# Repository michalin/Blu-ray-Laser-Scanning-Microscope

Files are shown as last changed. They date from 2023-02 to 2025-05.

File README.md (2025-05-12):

# Blu-ray Laser Microscope
In a way, CD-ROM and Blu-Ray drives already function like microscopes, using lasers to read the microscopic pits and lands on the surface of a CD or DVD. In the case of a Blu-Ray drive, an ultra precise blue (technically closer to violet in color) laser with a wavelength of 405 nanometers is focused on the surface of a disc, and how effectively that light is reflected back to the drive’s optical pickup unit determines whether a one or a zero has been detected.
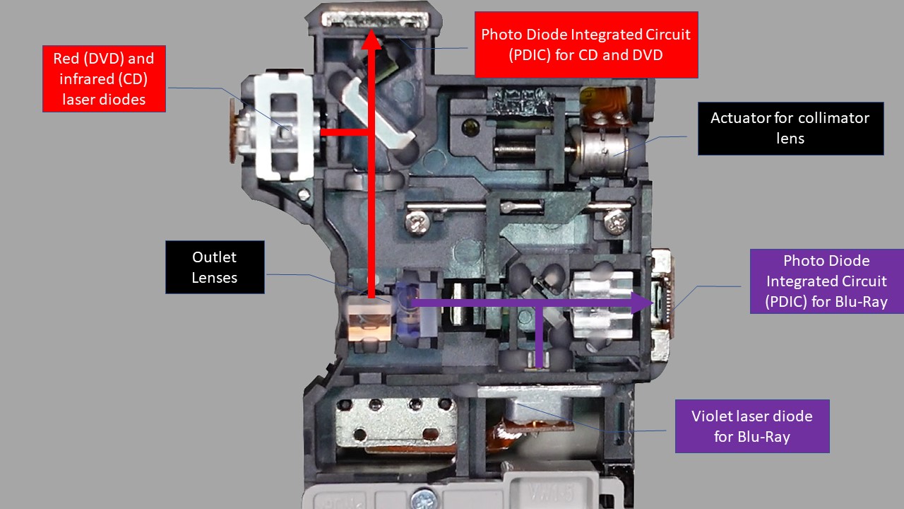
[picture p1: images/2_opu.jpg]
*Combined CD/DVD and Blu-ray optical pickup unit used in the project (BDP-10G)*</img>

But the sensors in the optical pickup unit can actually measure a wider range of light intensities—not just on or off— which facilitates a Blu-Ray drive’s error correction capabilities, and allows for the hardware to be repurposed for other uses. This is about repurposing a Blu-Ray pickup to build a simple scanning laser microscope. 
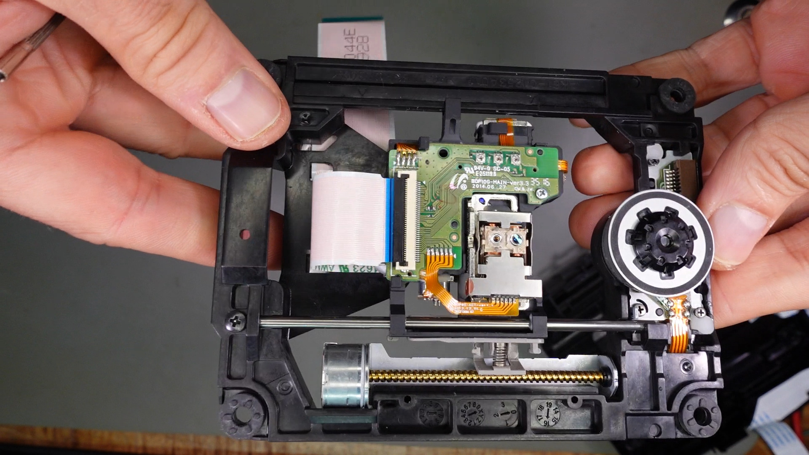
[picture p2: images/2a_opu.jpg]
*CD/DVD/Blu-ray drive with pickup from Samsung BD-J5900*</img>

A couple of custom-designed and manufactured plastic parts create a scanning bed for a sample that could move back in forth in one Y-direction (frame), while the laser itself shifted back and forth in x-direction (lines) by its surrounding "voice" coils.
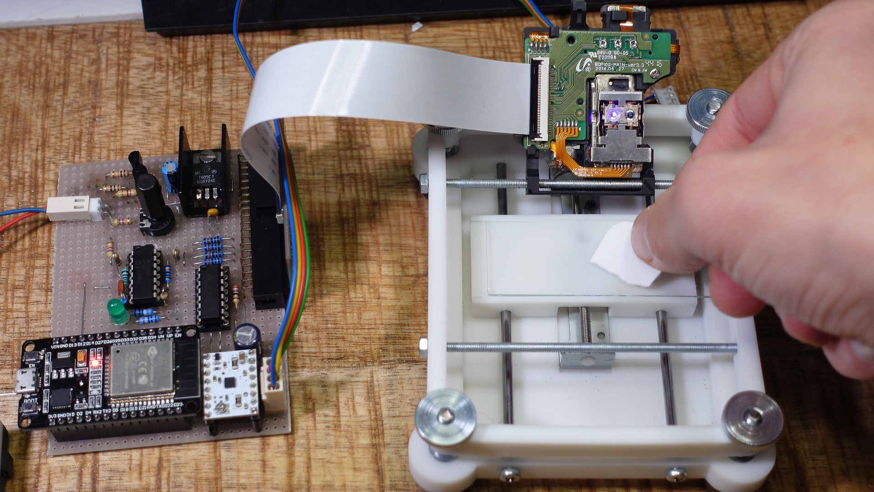
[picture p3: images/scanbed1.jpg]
*Scanning bed with electronics*</img>

Unlike an optical microscope, where the entirely of an object is imaged at once, a scanning laser microscope takes light intensity measurements in increments, moving across an object in a grid and assembling a magnified image pixel by pixel. 
A browser-based user interface written in HTML an Java Script allows to operate the device over WLAN.
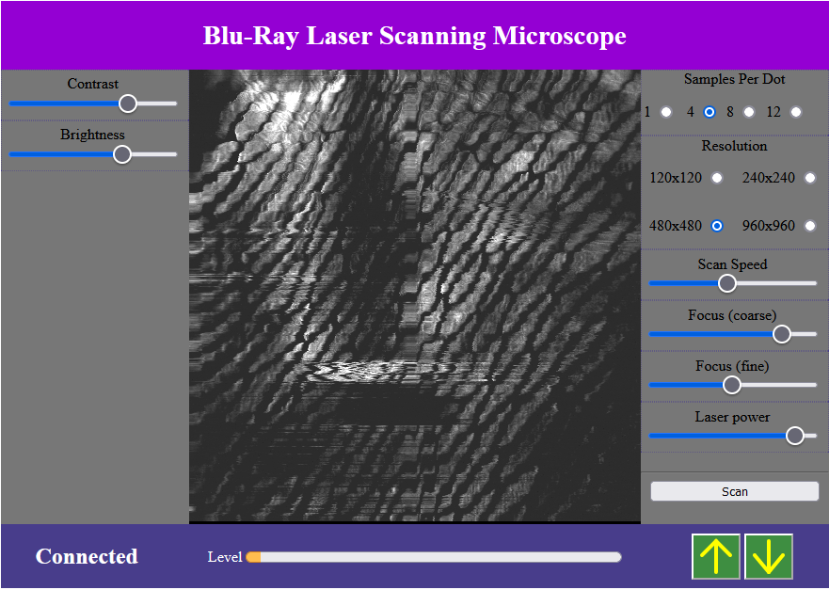
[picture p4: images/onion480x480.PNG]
*Web interface of Blu-ray microscope, showing onion cells*</img>

## Important Note
**The ESP32 API has changed from versions 2.X (based on ESP-IDF 4.4) to version 3.0 (based on ESP-IDF 5.1) of the Arduino ESP32 core. Only compiles against version 2.X.
Find more information here: [Migration from 2.x to 3.0](https://docs.espressif.com/projects/arduino-esp32/en/latest/migration_guides/2.x_to_3.0.html)**

---
## Preparing The Microscope
- Enter WLAN SSID and passphrase into the source code file `src.ino` and upload to ESP32 module.
- Copy `index.htm` and `opencv.js` to any directory on your PC and open `index.html` in your web browser.
- Adjust the reference voltage for the op-amps with Trimmer RV1 until the LED goes off and the level indicator on the bottom of the user interface shows a minimum.
- Adjust the current through the stepper motor with the trimmer on the STSPIN 220 driver module while the Up or Down button on the website is pressed until the object sled just moves smoothly. Warning: Too much current will overheat and burn the motor out.
- Place a slide in the recess of the specimen slide and a piece of paper on it. Flip down the OPU and turn the thumbscrews until the LED lights up.
---

## Taking Images
- Set the laser power and focus controls to their full extent
- Peep through the pickup lens from above and carefully position the specimen by hand and with the Up and Down buttons on the web interface until it is correctly placed.
- Slowly turn back the coarse focus control until the indicator swings out. Then adjust it with the fine focus control and the laser power control until it deflects about halfway.
- Perform a trial scan at low resolution and high scan speed. You can also adjust the parameters during the scan.
- Now try higher resolutions and/or lower scan speed and/or samples per dot to get a higher image quality.
  
---
## Watch Videos to Learn More
In Part one you will learn how I re-engineered an optical pickup unit from a broken Blu-ray player so that it can be used for a laser scanning microscope.  

<a href="https://youtu.be/liGuhbFh4IQ" alt="DIY Blu-Ray Laser Scanning Microscope #1: Making a Laser Microphone">
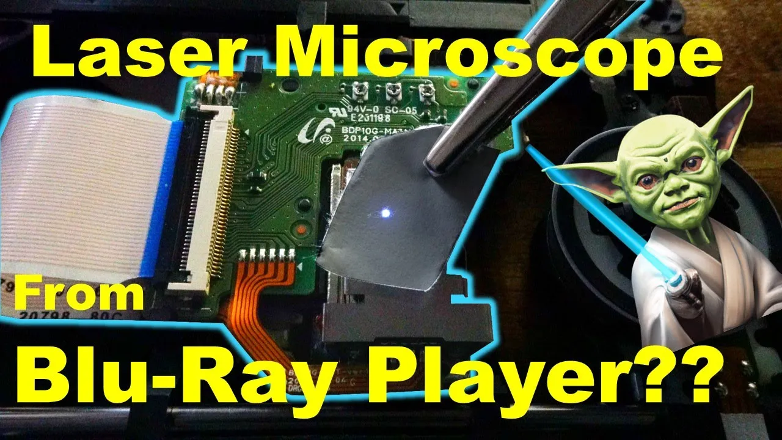
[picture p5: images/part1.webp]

</a>  

---
Part 2 is about a working prototype that builds on the existing CD/DVD/Blu-ray drive I salvaged from the Blu-ray player.  
<a href="https://youtu.be/Hkialty_8K4" alt="DIY Blu-Ray Laser Scanning Microscope #2: Shooting Images">
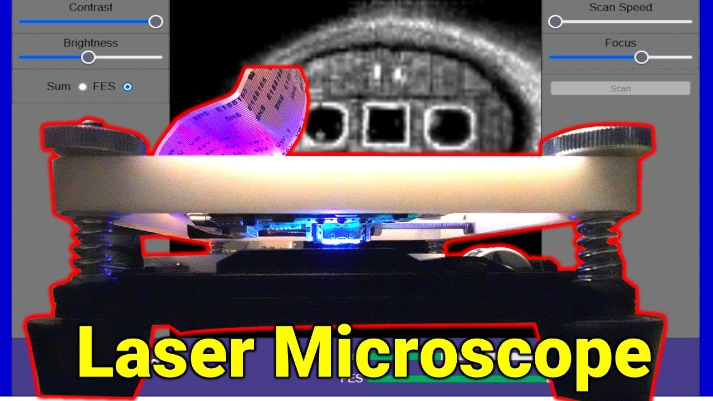
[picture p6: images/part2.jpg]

</a>

---
Part 3 shows how to build an improved version of the microscope from 3D printed parts and how to use it.  
<a href="https://youtu.be/xfuWbnMYOos" alt="DIY Blu-Ray Laser Scanning Microscope #3: Improvements And Tests">
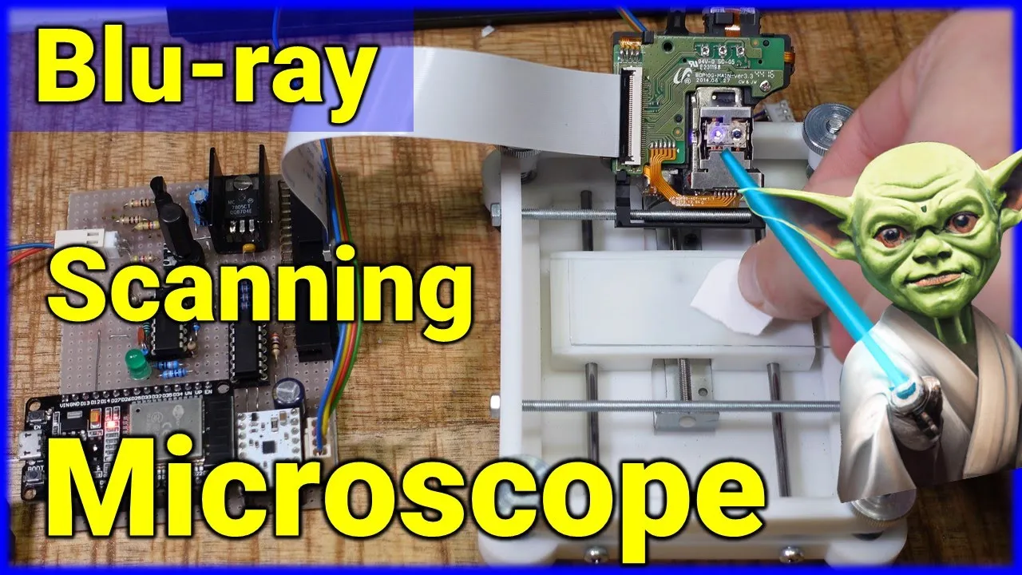
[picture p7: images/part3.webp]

</a>

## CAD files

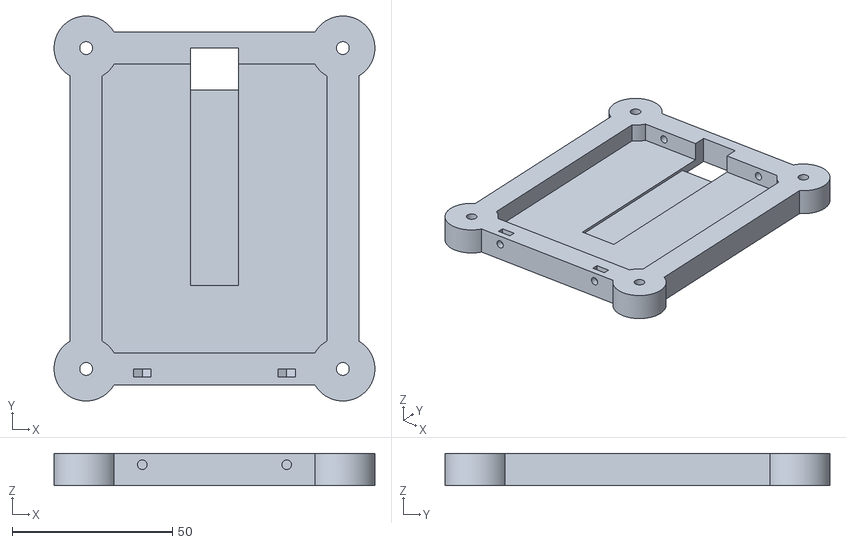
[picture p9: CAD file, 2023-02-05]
cad/bottom (Meshed).stl
100.0 x 120.0 x 10.0

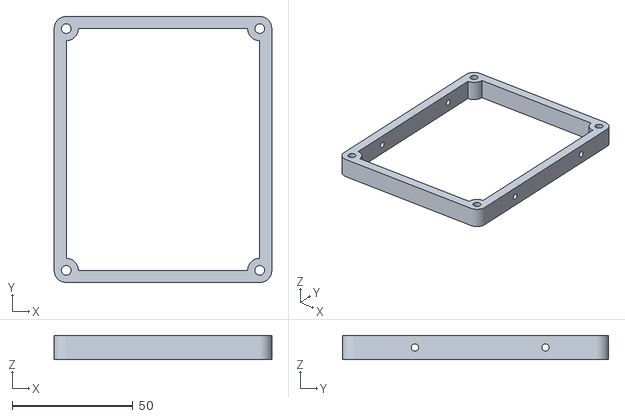
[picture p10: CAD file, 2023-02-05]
cad/top (Meshed).stl
90.0 x 110.0 x 10.0

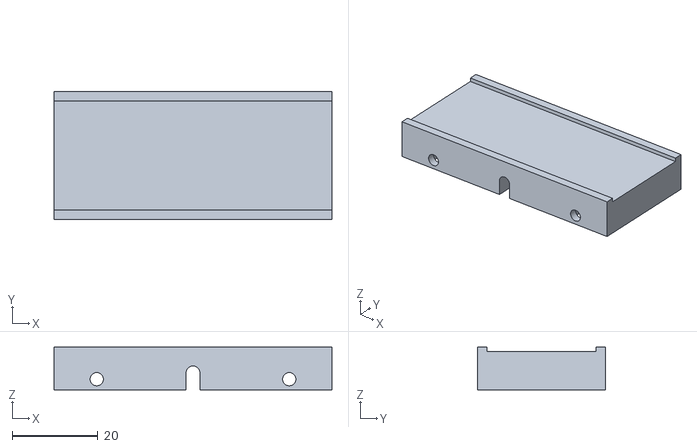
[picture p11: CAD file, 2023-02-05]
cad/obj_sled (Meshed).stl
65.0 x 30.0 x 10.0

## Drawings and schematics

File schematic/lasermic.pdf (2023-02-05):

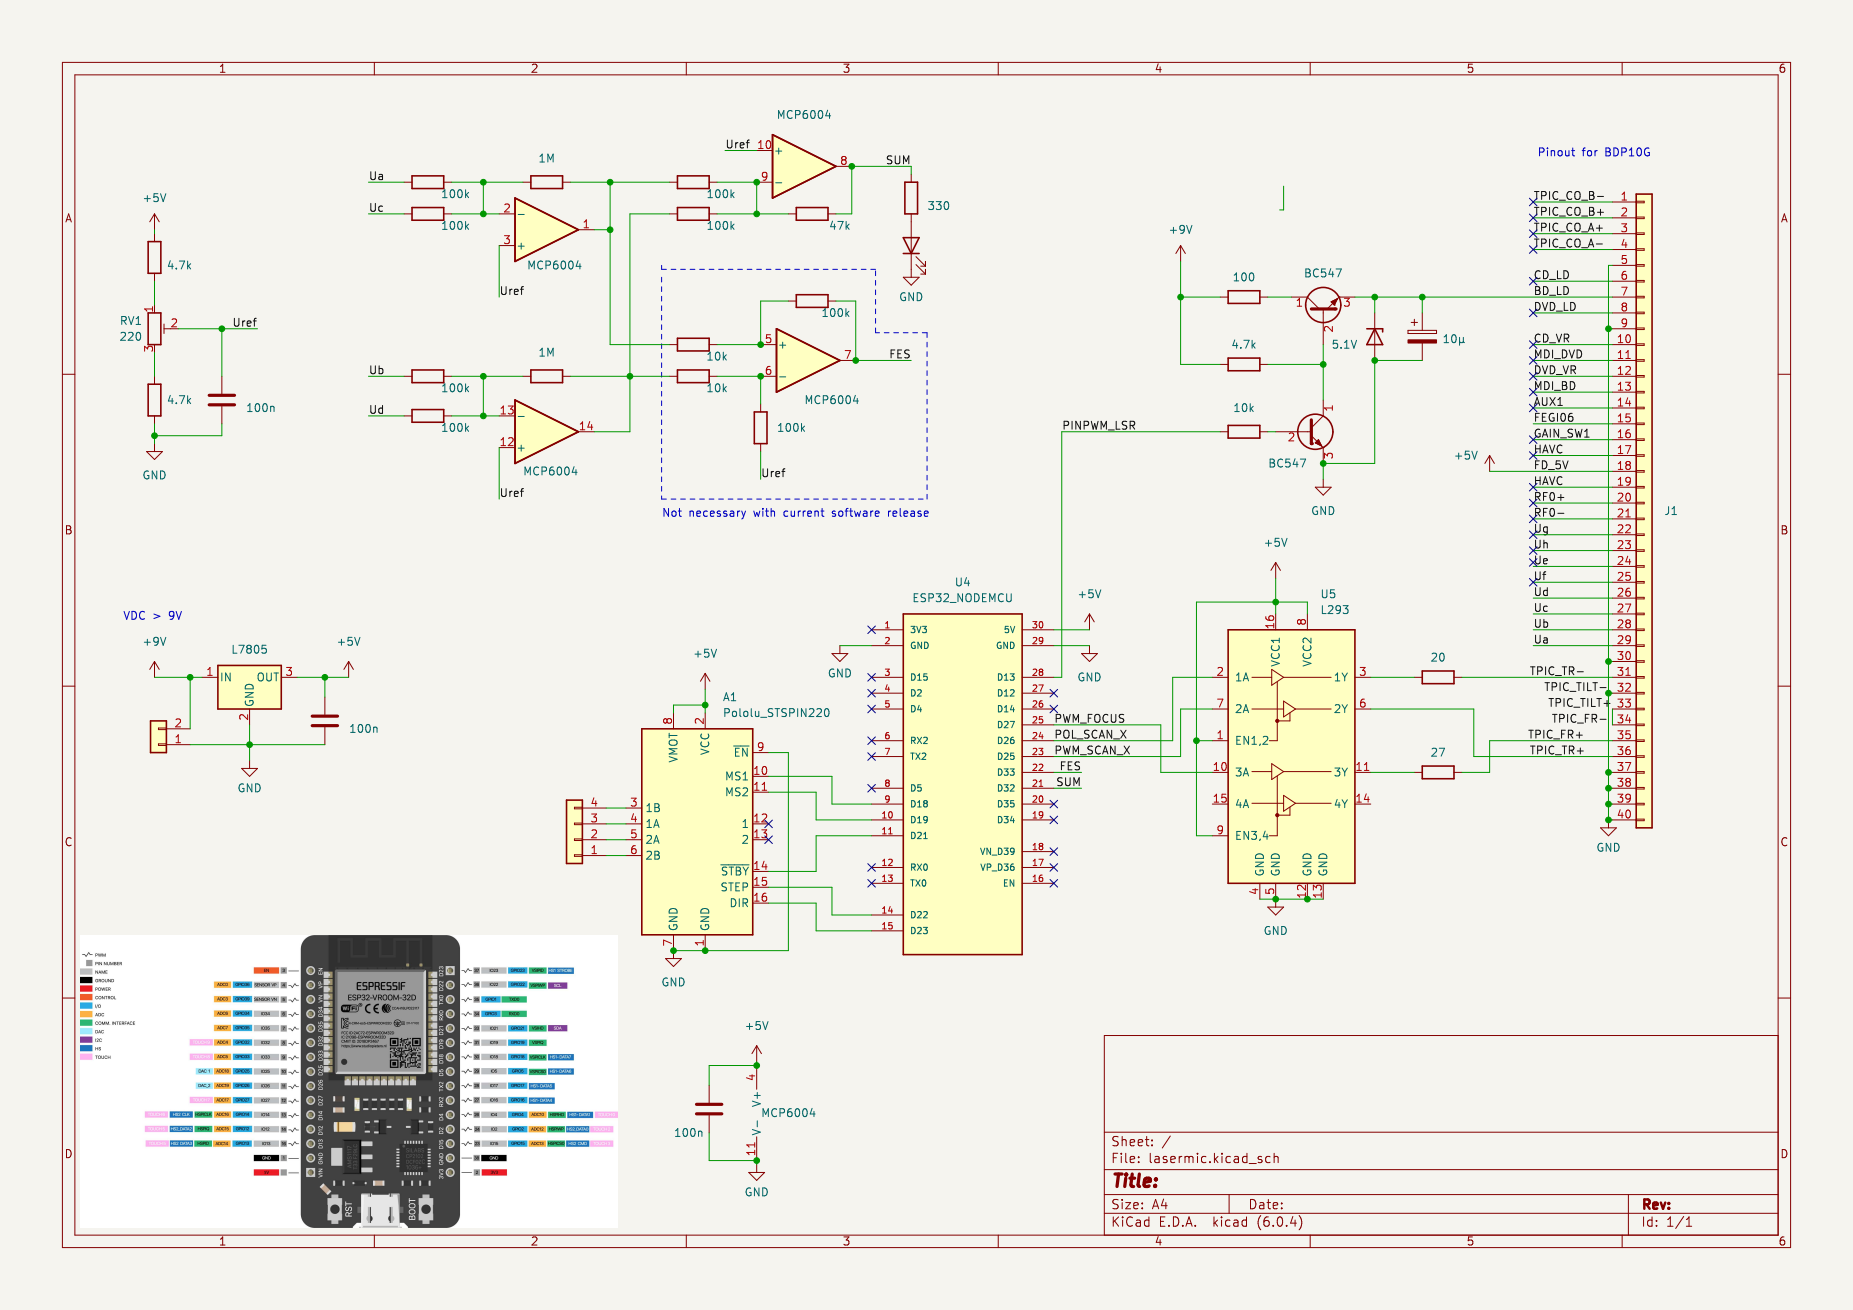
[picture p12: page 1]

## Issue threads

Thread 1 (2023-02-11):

Youtube images aren't showing up on ReadMe

zombodotcom, 2023-02-11:
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

this should fix it if you copy the markdown.

---
## Watch Videos to Learn More
In Part 1 you will see how I re-engineered an optical pickup unit from a broken Blu-ray player so that it can be used for a laser scanning microscope.

<a href="https://youtu.be/liGuhbFh4IQ" alt="DIY Blu-Ray Laser Scanning Microscope #1: Making a Laser Microphone">
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
</a>

---
Part 2 is about a working prototype that builds on the existing CD/DVD/Blu-ray drive I salvaged from the Blu-ray player.

<a href="https://youtu.be/Hkialty_8K4" alt="DIY Blu-Ray Laser Scanning Microscope #2: Shooting Images">
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
</a>

---
Part 3 shows how to build an improved version of the microscope from 3D printed parts and how to use it.

<a href="https://youtu.be/xfuWbnMYOos" alt="DIY Blu-Ray Laser Scanning Microscope #3: Improvements And Tests">
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
</a>

michalin, 2023-02-12:
Thank you. I fixed it.

Closed 2023-02-12.

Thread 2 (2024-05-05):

TPIC Resistor Value

SphaeroX, 2024-05-05:
R11 and R14 got no Footprints, but the value of 20 ad 27, is this the right resistor value?

i try to build a PCB for PCBWay, but i saw those are not connected.

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

michalin, 2024-05-06:
Yes, these are the values.

SphaeroX, 2024-05-14:
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

Here i am so far but i dont find any R20 and R27, can i use also R22 and R33 ?

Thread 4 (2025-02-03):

Pinout naming scheme

Caraffa-git, 2025-02-03:
Hi @michalin ,
could you please clarify the meaning of the labels in your schematic? The current names are not very intuitive, and I'm having trouble understanding the function of some pins:
- POL_SCAN_X
- PWM_SCAN_X
- TPIC_TR +/-
- TPIC_FT +/-

Also, why are TPIC_TILT+ and TPIC_FR- shorted together?

Your explanation would be much appreciated. Thanks!

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

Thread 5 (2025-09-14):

voice coil motor

GItWPP, 2025-09-14:
Hi there, I'm an electronics enthusiast looking to replicate your Blu-ray Laser Scanning Microscope project. I'm encountering some issues with the voice coil motor control. I see you've achieved up/down, left/right, and tilt movements for the voice coil motor, but this functionality isn't covered in the open-source documentation. Could you provide the source code for this part? Thanks!

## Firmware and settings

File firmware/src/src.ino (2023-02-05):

/* Copyright (C) 2022  Doctor Volt

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
 You should have received a copy of the GNU General Public License
 along with this program.  If not, see <https://www.gnu.org/licenses/>.
*/

// #include <Arduino.h>
#include <ArduinoJson.h>
//#include "driver/ledc.h"

#define PINSTEPY_M1 18
#define PINSTEPY_M2 19
#define PINSTEPY_SLP 21
#define PINSTEPY_DIR 22
#define PINSTEPY_STP 23
#define PINPWM_SCAN_X 25
#define PINPOL_SCAN_X 26
#define PINPWN_FOCUS 27

#define PIN_SUM 32
#define PIN_FES 33
#define PINPWM_LSR 13
#define ACTIVE LOW
#define PASSIVE HIGH
#define MAX_SAMPLES 16
enum CMD
{
  CMD_IDLE,
  SCAN,
  STOP,
  FOCUS,
  GO_UP,
  GO_DN,
  GO_STOP
};
#define DIRY_UP 1
#define DIRY_DN 0
#define PWM_SCN_MAX_BITS 9
#define PWM_FOC_BITS 10
#define PWM_LSR_BITS 8


const char *ssid = "WLAN-KEY";
const char *password = "passphrase";
// const int ledPin = LED_BUILTIN;
const int PWMScnFreq = 40000000 >> PWM_SCN_MAX_BITS; // PWM Frequency for X-Scan for max. resolution
const int PWMChanScn = 0;     // PWM Channel for X-Scan
const int PWMFocFreq = 40000000 >> PWM_FOC_BITS;
const int PWMChanFoc = 2; // PWM Channel for focus
const int PWMLsrFreq = 100000;
const int PWMChanLsr = 4; // PWM Channel for laser
const int PWMChanSld = 6; // PWM Channel for manual sled positioning
int PWMRes;               // = (1 << PWMResBits) - 1;
int resolution;           // = 2 * (1 << PWMResBits) - 1;
// int YRes;
int scan_speed;
int nsamples; // Samples per dot for averaging
struct /*__attribute__((__packed__))*/ Point
{
  uint16_t C1;
  // uint16_t C2;
};
typedef uint16_t CVPoint;
CVPoint *linebuf;
portMUX_TYPE timerMux = portMUX_INITIALIZER_UNLOCKED;
volatile SemaphoreHandle_t scanSemaphore;
TaskHandle_t taskHandle;

// Function declarations for web.cpp
void web_init(const char *ssid, const char *password);
void web_write(const char *data);
// void web_write_event(const char *event);
void web_cleanup();

// void scan_(void*);

// Macro to configure the STSPIN220 for 64 microsteps
#define STS220SET                      \
  digitalWrite(PINSTEPY_SLP, ACTIVE);  \
  digitalWrite(PINSTEPY_STP, LOW);     \
  digitalWrite(PINSTEPY_DIR, HIGH);    \
  digitalWrite(PINSTEPY_SLP, PASSIVE); \
  vTaskDelay(10);

void setXscan(int x) // Position of lens
{
  int d;
  if (x >= 0)
  {
    d = PWMRes - x - resolution / 30; // The "resolution/xx fixes the glitch arond the zero position"
    digitalWrite(PINPOL_SCAN_X, HIGH);
  }
  else
  {
    d = -x;
    digitalWrite(PINPOL_SCAN_X, LOW);
  }
  //  int d = (x >= 0) ? PWMRes - x : -x;
  //Serial.printf("x: %d, d: %d\n", x, d);
  //  digitalWrite(PINPOL_SCAN_X, (x >= 0));
  ledcWrite(PWMChanScn, d);
}

void scanX(int speed, CVPoint *linebuf)
{
  for (int i = 1; i <= 16; i++) // Move back lens smoothly before scanning to prevent bouncing
  {
    setXscan(-i * resolution / 32);
    // Serial.printf("%d", -i*PWMRes/8);
    vTaskDelay(10);
  }
  for (int scanX = -resolution / 2; scanX <= resolution / 2 - 1; scanX++)
  {
    setXscan(scanX);
    delayMicroseconds(1550 - 100 * speed);
    int c1 = 0;
    for (int i = 0; i < nsamples; i++)
    {
      c1 += analogRead(PIN_SUM);
      // c2 += analogRead(PIN_FES);
    }
    linebuf[resolution / 2 + scanX] = 16 * (c1 / nsamples); // Sum
  }
  setXscan(0); //Neutral position
}

/* This must be started as task to prevent triggering the async_tcp watchdog*/
void scan(void *task_break)
{
  const int nSteps = 1280;   // Will do one revolution (20*64 microsteps)
  static int microsteps = 0; // Number of microsteps passed
  const int pre_steps = 200;  // Number of steps the motor takes before scanning for the leadscrew to gain grip.
  Serial.println("Start scanning");
  STS220SET

  int yskip = 1 + floor(nSteps / (PWMRes + 1));

  digitalWrite(PINSTEPY_DIR, DIRY_UP);
  for (int i = 0; i < yskip * resolution / 2; i++)
  {
    digitalWrite(PINSTEPY_STP, HIGH);
    vTaskDelay(1);
    digitalWrite(PINSTEPY_STP, LOW);
    vTaskDelay(1);
    microsteps--;
  }
  // Advance the sled a bit, so that the leadscrew gets grip.
  digitalWrite(PINSTEPY_DIR, DIRY_DN);
  for (int i = 0; i < pre_steps / yskip; i++)
  {
    digitalWrite(PINSTEPY_STP, HIGH);
    vTaskDelay(1);
    digitalWrite(PINSTEPY_STP, LOW);
    vTaskDelay(1);
    microsteps++;
  }

  for (int i = 0; (i < resolution) && (!*((bool *)task_break)); i++)
  {
    scanX(scan_speed, linebuf);     // Scan line Forwards
    for (int i = 0; i < yskip; i++) // Forward by ySkip microsteps
    {
      digitalWrite(PINSTEPY_STP, HIGH);
      vTaskDelay(1);
      digitalWrite(PINSTEPY_STP, LOW);
      vTaskDelay(1);
      microsteps++;
    }
    xSemaphoreGive(scanSemaphore); // This triggers sending of the line in the loop() function
    vTaskSuspend(NULL);            // Suspend task during data transfer
    //if(*(bool*)task_break) break;
  }
  Serial.printf("Scan completed: %d\n", *((bool *)task_break));

  // Move sled back to intitial y position
  digitalWrite(PINSTEPY_DIR, DIRY_UP);
  for (int i = 0; i < microsteps; i++)
  {
    digitalWrite(PINSTEPY_STP, HIGH);
    delayMicroseconds(200);
    digitalWrite(PINSTEPY_STP, LOW);
    delayMicroseconds(200);
  }
  microsteps = 0;
  digitalWrite(PINSTEPY_SLP, ACTIVE);
  digitalWrite(PINPWM_SCAN_X, LOW);
  ledcWrite(PWMChanScn, 0);
  digitalWrite(PINPOL_SCAN_X, LOW);
  web_write("stop");
  vTaskDelete(NULL);
}

void handleWebMessage(const char *data, size_t len)
{
  DynamicJsonDocument jdoc(1024);
  deserializeJson(jdoc, data);
  static bool taskBreak;

  if (nsamples != (int)jdoc["nsamples"])
  {
    nsamples = jdoc["nsamples"];
    // Serial.printf("Number of samples per dot: %d\n", nsamples);
  }
  if (scan_speed != (int)jdoc["speed"])
  {
    scan_speed = jdoc["speed"];
    // Serial.printf("speed: %d\n", scan_speed);
  }
  static int pwmbits;
  if (pwmbits != (int)jdoc["pwmbits"])
  {
    pwmbits = jdoc["pwmbits"];
    Serial.printf("pwmbits: %d\n", pwmbits);
    ledcSetup(PWMChanScn, PWMScnFreq, pwmbits);
    PWMRes = (1 << pwmbits) - 1;
    resolution = 2 * (1 << pwmbits) - (1 << pwmbits - 3);
    Serial.printf("Resolution: %d\n", resolution);
  }
  static int focus;
  if (focus != (int)jdoc["focus"])
  {
    focus = jdoc["focus"];
    // Serial.printf("focus: %d\n", focus);
    ledcWrite(PWMChanFoc, focus);
  }
  static int laser;
  if (laser != (int)jdoc["laser"])
  {
    laser = jdoc["laser"];
    // Serial.printf("laser: %d\n", laser);
    ledcWrite(PWMChanLsr, laser);
  }
  static int xcoil;
  if (xcoil != (int)jdoc["xcoil"])
  {
    xcoil = jdoc["xcoil"];
    Serial.printf("xcoil: %d\n", xcoil);
    setXscan(xcoil);
  }

  switch ((int)jdoc["cmd"])
  {
  case CMD::SCAN:
    taskBreak = 0;
    xTaskCreate(scan, "scan", 16000, &taskBreak, 1, &taskHandle);
    break;
  case CMD::STOP:
    taskBreak = 1;
    break;
  case CMD::GO_UP:
  case CMD::GO_DN:
    // Serial.print("Move Sled ");
    STS220SET;
    (int)jdoc["cmd"] == GO_UP
        ? digitalWrite(PINSTEPY_DIR, DIRY_UP)
        : digitalWrite(PINSTEPY_DIR, DIRY_DN);
    ledcAttachPin(PINSTEPY_STP, PWMChanSld);
    ledcWriteTone(PWMChanSld, 100 * (scan_speed + 1));
    break;
  case CMD::GO_STOP:
    // Serial.println("Stop sled");
    ledcDetachPin(PINSTEPY_STP);
    digitalWrite(PINSTEPY_SLP, ACTIVE);
    break;
  }
}

/*void ARDUINO_ISR_ATTR onTimer()
{
  portENTER_CRITICAL_ISR(&timerMux);
  portEXIT_CRITICAL_ISR(&timerMux);
  xSemaphoreGiveFromISR(timerSemaphore, NULL);
}*/

void setup()
{
  Serial.begin(115200);
  // digitalWrite(ledPin, LOW);
  scanSemaphore = xSemaphoreCreateBinary();
  // hw_timer_t *timer = timerBegin(0, 80, true);
  // timerAttachInterrupt(timer, &onTimer, true);
  // timerAlarmWrite(timer, 100000, true);
  // timerAlarmEnable(timer);
  linebuf = (CVPoint*)calloc(sizeof(CVPoint), 2 << PWM_SCN_MAX_BITS);

  pinMode(PINSTEPY_SLP, OUTPUT);
  digitalWrite(PINSTEPY_SLP, ACTIVE);

  pinMode(PINSTEPY_M1, OUTPUT);
  pinMode(PINSTEPY_M2, OUTPUT);
  pinMode(PINSTEPY_STP, OUTPUT);
  pinMode(PINSTEPY_DIR, OUTPUT);

  // Set M1 and M2 for motor driver
  digitalWrite(PINSTEPY_M1, HIGH);
  digitalWrite(PINSTEPY_M2, HIGH);

  pinMode(PINPOL_SCAN_X, OUTPUT);
  adcAttachPin(PIN_SUM);
  adcAttachPin(PIN_FES);

  ledcSetup(PWMChanFoc, PWMFocFreq, PWM_FOC_BITS);
  ledcSetup(PWMChanLsr, PWMLsrFreq, PWM_LSR_BITS);
  ledcSetup(PWMChanSld, 0, 1);
  ledcAttachPin(PINPWN_FOCUS, PWMChanFoc);
  ledcAttachPin(PINPWM_LSR, PWMChanLsr);
  ledcAttachPin(PINPWM_SCAN_X, PWMChanScn);
  // handleWebMessage("{\"speed\":2,\"pwmbits\":6,\"yres\":128,\"cmd\":1}", 35);
  web_init(ssid, password);
}

void loop()
{
  char buf[16];
  if (xSemaphoreTake(scanSemaphore, 100) == pdTRUE)
  {
    String line;
    for (int i = 0; i < resolution; i++)
    {
      // sprintf(buf, "%d,%d,", linebuf[i].C1, linebuf[i].C2);
      sprintf(buf, "%d,", linebuf[i]);
      line += String(buf);
    }
    line[line.length() - 1] = 0; // Remove comma */
    // Serial.println(line);
    web_write(line.c_str());
    vTaskResume(taskHandle);
  }
  else
  {
    sprintf(buf, "{\"SUM\": %d}", analogRead(PIN_SUM));
    web_write(buf);
  }
  // Serial.println("loop");
  web_cleanup();
}

// Create test pattern
void scan_(void *task_break)
{
  Serial.printf("xres: %d, yres: %d, PWMRes: %d\n", resolution, resolution, PWMRes);
  for (int i = 0; (i < resolution) && (!*((bool *)task_break)); i++)
  {
    for (int scanX = -resolution / 2; scanX <= resolution / 2; scanX++)
    {
      if (scanX % 16)
        linebuf[resolution / 2 + scanX] = 256 * (resolution / 2 + scanX); // Sum
    }

    xSemaphoreGive(scanSemaphore); // This triggers sending of the line in the loop() function
    vTaskSuspend(NULL);
  }
  web_write("stop");
  vTaskDelete(NULL);
}

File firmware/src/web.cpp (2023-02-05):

/*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
 You should have received a copy of the GNU General Public License
 along with this program.  If not, see <https://www.gnu.org/licenses></https:>.
*/

#define LOCAL_WEB //Website located on PC
//#define USE_OTA

#include <WiFi.h>
#include <AsyncTCP.h>
#include <ESPAsyncWebServer.h>
#ifndef LOCAL_WEB
#include <SPIFFS.h>
#endif
#include <mdns.h>
#ifdef USE_OTA
//#include <AsyncElegantOTA.h>
#endif

// mdns hostname
const char *hostname = "lasermic.local";

void handleWebMessage(const char *data, size_t len);

// Create AsyncWebServer object on port 80
AsyncWebServer server(80);
AsyncWebSocket ws("/ws");
//AsyncEventSource es("/es");

void onEvent(AsyncWebSocket *server, AsyncWebSocketClient *client, AwsEventType type,
             void *arg, uint8_t *data, size_t len)
{
  switch (type)
  {
  case WS_EVT_CONNECT:
    Serial.printf("WebSocket client #%u connected from %s\n", client->id(), client->remoteIP().toString().c_str());
    break;
  case WS_EVT_DISCONNECT:
    Serial.printf("WebSocket client #%u disconnected\n", client->id());
    break;
  case WS_EVT_DATA:
    // handleWebSocketMessage(arg, data, len);
    {
      AwsFrameInfo *info = (AwsFrameInfo *)arg;
      if (info->final && info->index == 0 && info->len == len && info->opcode == WS_TEXT)
      {
        handleWebMessage((const char *)data, len);
      }
    }
    break;
  case WS_EVT_PONG:
    Serial.println("WebSocket Pong:");
  case WS_EVT_ERROR:
    Serial.println("WebSocket Error");
  }
}

String processor(const String &var)
{
  Serial.print("processor");
  Serial.println(var);
  if (var == "STATE")
  {
  }
  return "Hello";
}

void web_init(const char *ssid, const char *password)
{
  // Serial port for debugging purposes

  // Connect to Wi-Fi
  WiFi.begin(ssid, password);
  Serial.print("Connecting to WiFi");
  while (WiFi.status() != WL_CONNECTED)
  {
    Serial.print(".");
    delay(500);
  }
  // Print ESP Local IP Address
  Serial.println();
  Serial.println("WiFi Connected");

  // Assign DNS name
  mdns_init();
  mdns_hostname_set(hostname);

  ws.onEvent(onEvent);
  server.addHandler(&ws);

  // Initialize SPIFFS
  #ifndef LOCAL_WEB
  Serial.printf("Open http://%s in browser\r\n", hostname);
  if (!SPIFFS.begin(true))
  {
    Serial.println("An Error has occurred while mounting SPIFFS");
    return;
  }
  server.serveStatic("/", SPIFFS, "/");
  #endif

  /*Event source initialization*/
  /*es.onConnect([](AsyncEventSourceClient *client)
               {
    //Serial.println("es.onConnect");
    if(client->lastId()){
      Serial.printf("Event Client reconnected! Last message ID: %u\n", client->lastId());
    }
    if(client->connected()){
      Serial.println("Event source connected");
    } });*/
  
  // Magic to allow access to event server from anywhere
  DefaultHeaders::Instance().addHeader(F("Access-Control-Allow-Origin"), F("*"));
  //DefaultHeaders::Instance().addHeader(F("Access-Control-Allow-Credentials"), F("true"));
  #ifdef USE_OTA
  AsyncElegantOTA.begin(&server);
  #endif
   // Start server
  server.begin();
  //server.addHandler(&es);
}

/*void web_write_event(const char *data)
{
  // ws.textAll((const char*)buffer, len);
  while(es.avgPacketsWaiting())
  {
    Serial.printf("waiting: %d\n",es.avgPacketsWaiting());
    vTaskDelay(1000);
  }
  es.send(data);
}*/

void web_write(const char *data)
{
  ws.textAll(data);
  while(!ws.availableForWriteAll())
  {
    //Serial.println("Waiting for websocket");
    vTaskDelay(10);
  }
  // es.send(data, NULL);
}

void web_cleanup()
{
  ws.cleanupClients();
}

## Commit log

2023-02-05 Version 1.0
    [bottom (Meshed).stl, lasermic.kicad_sch, obj_sled (Meshed).stl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]
2025-05-12 Update README.md
    No more supported by ESP Arduino core V3.x or newer.
2025-05-12 Update README.md
    Arduino ESP32 core V3.0 and newer no more supported.

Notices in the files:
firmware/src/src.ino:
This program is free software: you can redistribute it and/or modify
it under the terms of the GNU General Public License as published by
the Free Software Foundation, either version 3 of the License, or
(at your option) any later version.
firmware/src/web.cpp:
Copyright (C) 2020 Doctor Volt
